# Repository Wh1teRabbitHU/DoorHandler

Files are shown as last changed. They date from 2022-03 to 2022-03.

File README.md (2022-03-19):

# DoorHandler
This is a door handler/extender electronic project to monitor (almost) any type of door bells using a light sensor, a transmitter and a receiver module. The light sensor periodically checks the door phone if the signal is lit or not and sends a pulse to the receiver, which can be anywhere in the house and can provide visual and/or auditory signals to the home owners.

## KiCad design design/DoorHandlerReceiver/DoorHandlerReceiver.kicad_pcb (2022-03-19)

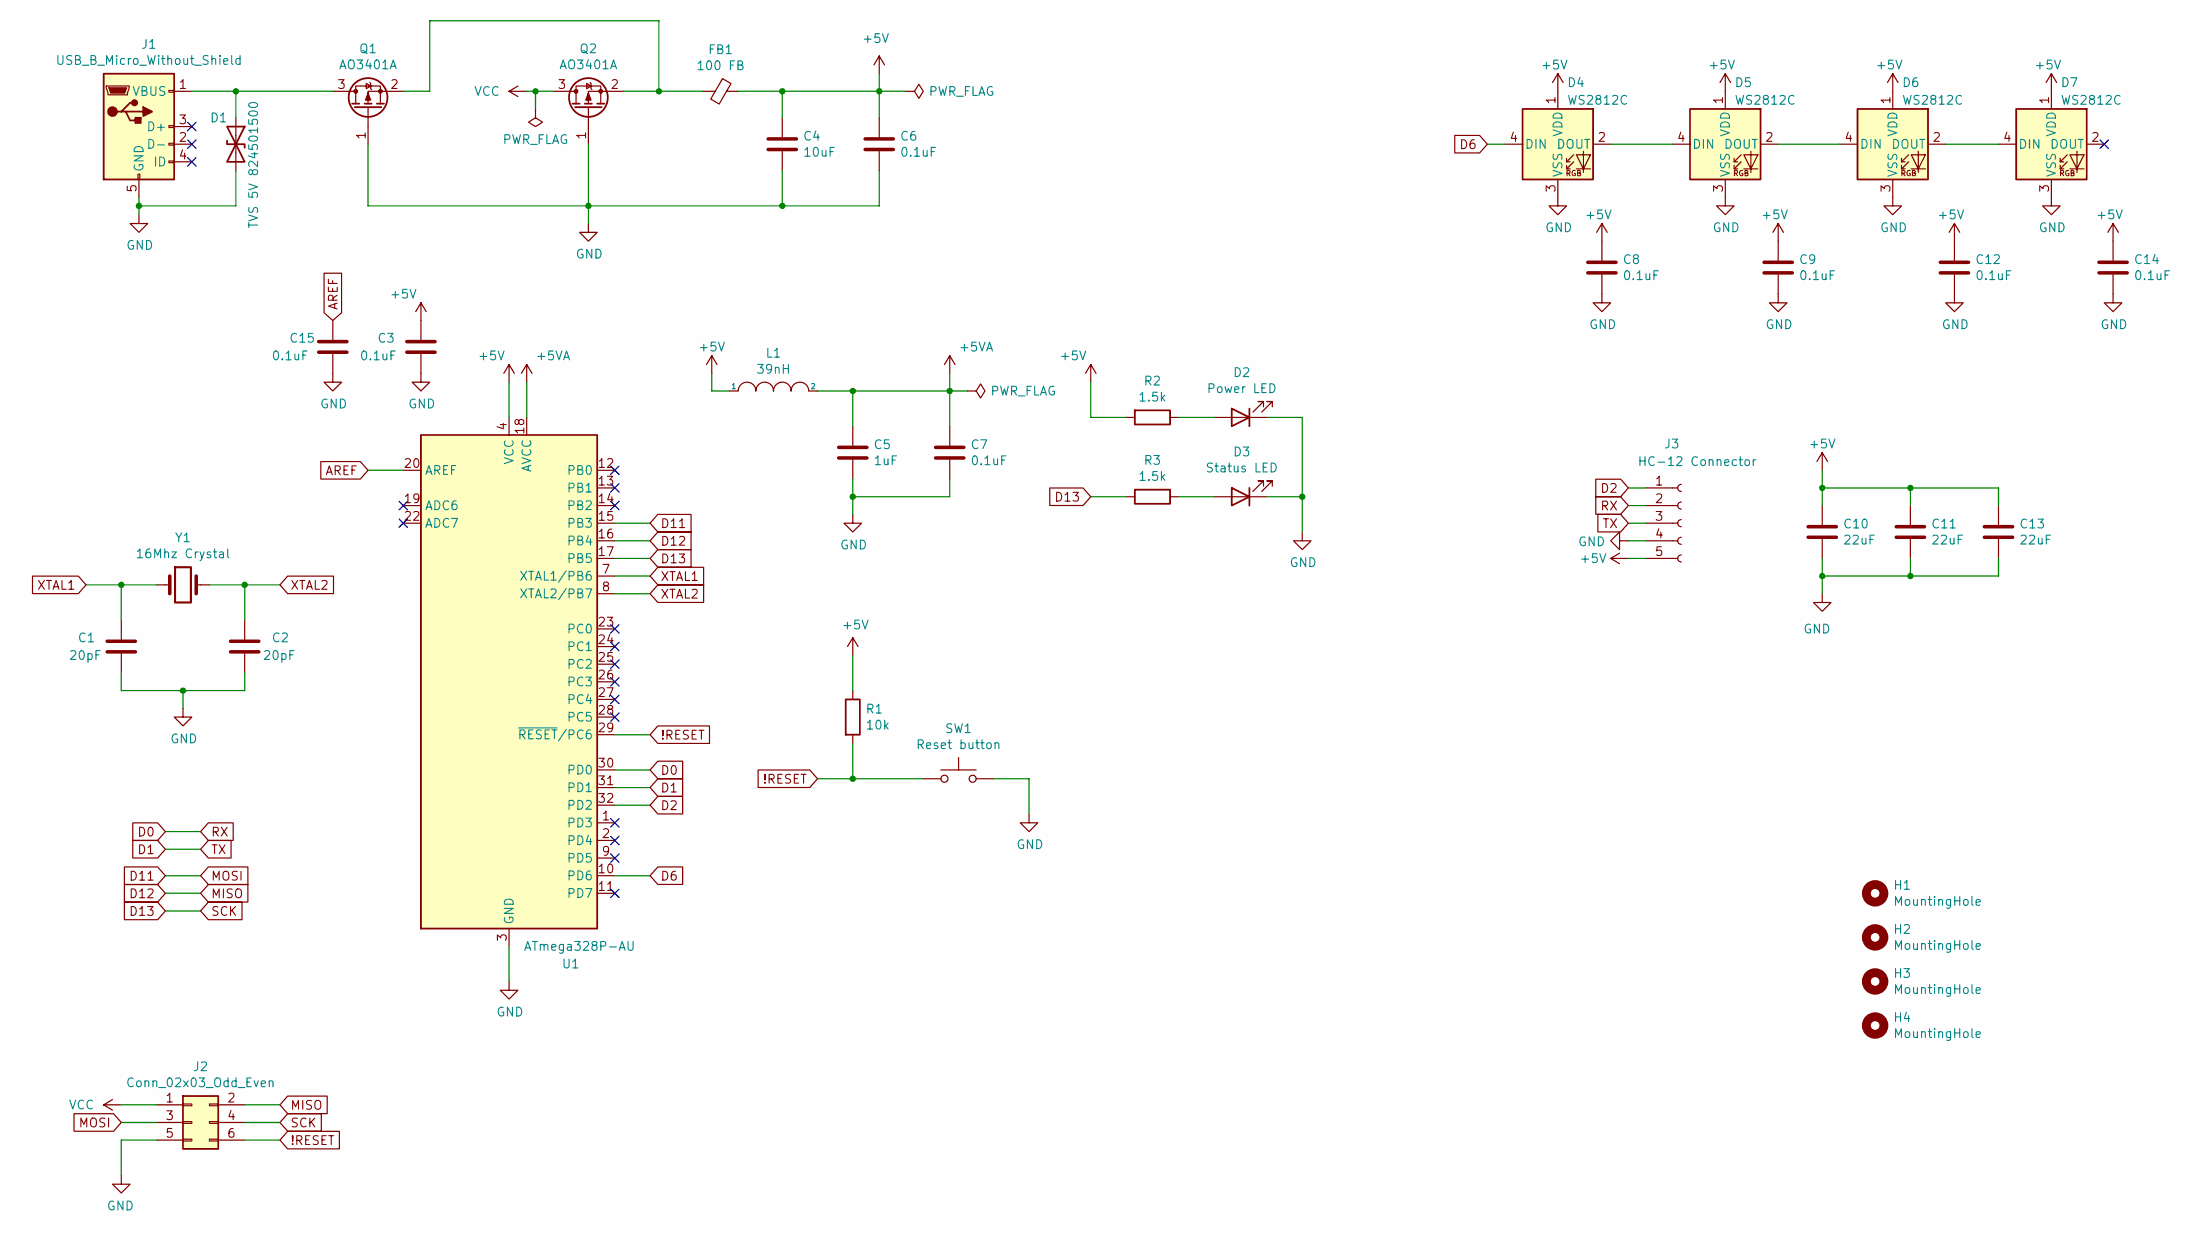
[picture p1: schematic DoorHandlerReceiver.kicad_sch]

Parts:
C1, C2: 20pF; C_0805_2012Metric
C3, C6, C7, C8, C9, C12, C14, C15: 0.1uF; C_0805_2012Metric
C4: 10uF; C_1206_3216Metric
C5: 1uF; C_0805_2012Metric
C10, C11, C13: 22uF; C_0805_2012Metric
D1: TVS 5V 824501500; D_SMA
D2: Power LED; LED_0603_1608Metric
D3: Status LED; LED_0603_1608Metric
D4, D5, D6, D7: WS2812C; LED_WS2812B_PLCC4_5.0x5.0mm_P3.2mm
FB1: 100 FB; L_0805_2012Metric_Pad1.05x1.20mm_HandSolder
H1, H2, H3, H4: MountingHole; MountingHole_3.2mm_M3_Pad_Via
J1: USB_B_Micro_Without_Shield; Micro_USB_B_Female
J2: Conn_02x03_Odd_Even; PinSocket_2x03_P2.54mm_Vertical
J3: HC-12 Connector; PinSocket_1x05_P2.54mm_Vertical
L1: 39nH; L_0805_2012Metric_Pad1.15x1.40mm_HandSolder
Q1, Q2: AO3401A; SOT-23
R1: 10k; R_1206_3216Metric
R2, R3: 1.5k; R_1206_3216Metric
SW1: Reset button; SW_SPST_TL3342
U1: ATmega328P-AU; TQFP-32_7x7mm_P0.8mm
Y1: 16Mhz Crystal; Crystal_HC49-U_Vertical

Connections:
!RESET: J2.6, R1.2, SW1.1, U1.29 (~RESET/PC6)
+5V: C3.1, C4.1, C6.1, C8.1, C9.1, C10.1, C11.1, C12.1, C13.1, C14.1, D4.1 (VDD), D5.1 (VDD), D6.1 (VDD), D7.1 (VDD), FB1.1, J3.5, L1.1, R1.1, R2.2, U1.4 (VCC), U1.6 (VCC)
+5VA: C5.1, C7.1, L1.2, U1.18 (AVCC)
AREF: C15.1, U1.20 (AREF)
D0: J3.2, U1.30 (PD0)
D1: J3.3, U1.31 (PD1)
D2: J3.1, U1.32 (PD2)
D6: D4.4 (DIN), U1.10 (PD6)
D11: J2.3, U1.15 (PB3)
D12: J2.2, U1.16 (PB4)
D13: J2.4, R3.2, U1.17 (PB5)
GND: C1.2, C2.2, C3.2, C4.2, C5.2, C6.2, C7.2, C8.2, C9.2, C10.2, C11.2, C12.2, C13.2, C14.2, C15.2, D1.2 (A2), D2.1 (K), D3.1 (K), D4.3 (VSS), D5.3 (VSS), D6.3 (VSS), D7.3 (VSS), J1.5 (GND), J2.5, J3.4, Q1.1 (G), Q2.1 (G), SW1.2, U1.3 (GND), U1.5 (GND), U1.21 (GND)
unnamed: D1.1 (A1), J1.1 (VBUS), Q1.3 (D)
unnamed: D2.2 (A), R2.1
unnamed: D3.2 (A), R3.1
unnamed: D4.2 (DOUT), D5.4 (DIN)
unnamed: D5.2 (DOUT), D6.4 (DIN)
unnamed: D6.2 (DOUT), D7.4 (DIN)
unnamed: FB1.2, Q1.2 (S), Q2.2 (S)
VCC: J2.1, Q2.3 (D)
XTAL1: C1.1, U1.7 (XTAL1/PB6), Y1.1
XTAL2: C2.1, U1.8 (XTAL2/PB7), Y1.2

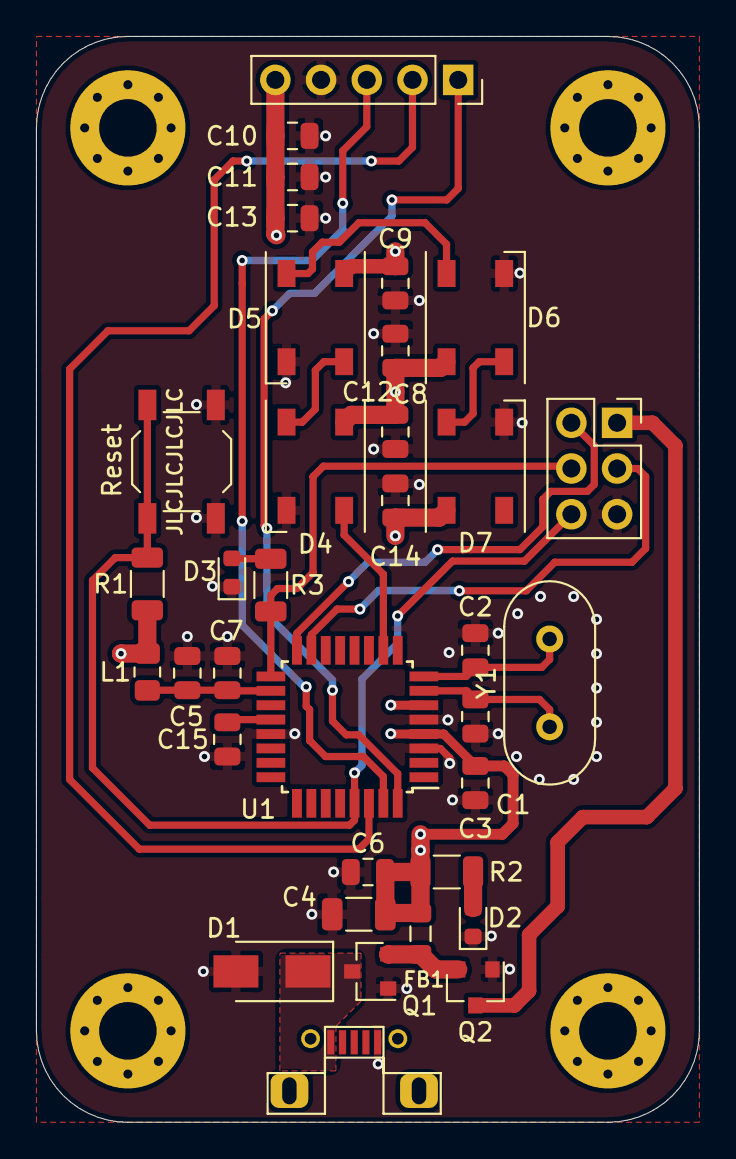
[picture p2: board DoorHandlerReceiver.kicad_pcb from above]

Board: 4 copper layers, 36.8 x 60.3 mm, 39 parts (0 on the bottom side), 22 nets.

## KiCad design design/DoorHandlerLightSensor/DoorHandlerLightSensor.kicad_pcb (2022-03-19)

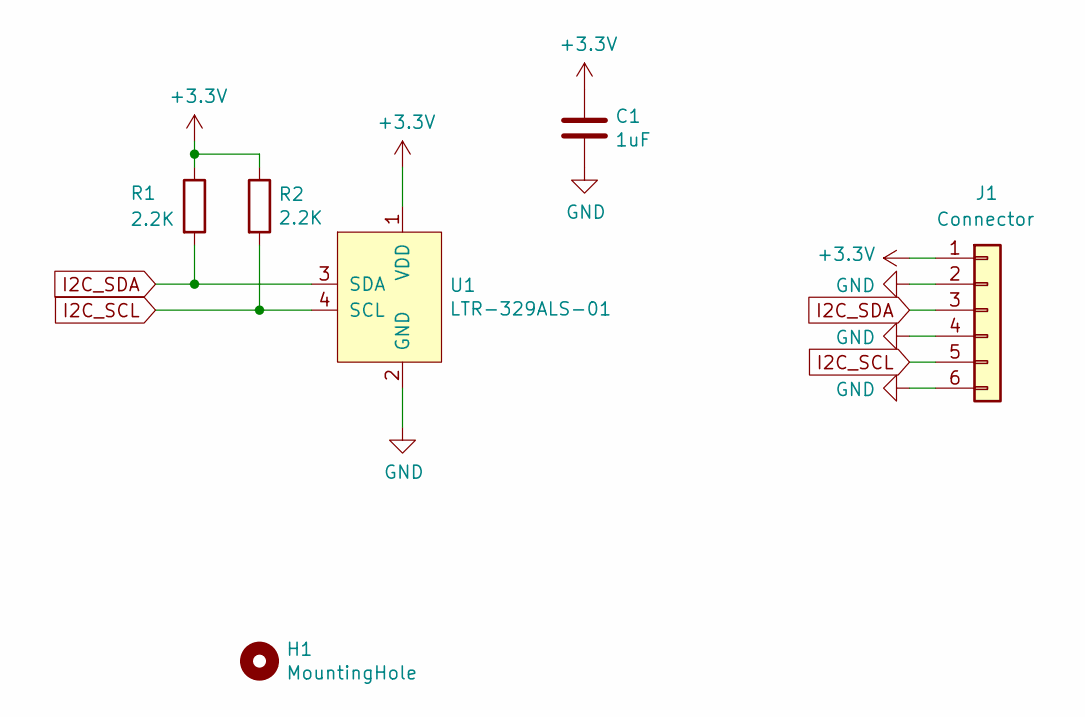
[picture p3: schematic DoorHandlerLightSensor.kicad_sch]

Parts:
C1: 1uF; C_0805_2012Metric
H1: MountingHole; MountingHole_3.2mm_M3_Pad_Via
J1: Connector; AFA07-S06FCA-00
R1, R2: 2.2K; R_1206_3216Metric
U1: LTR-329ALS-01

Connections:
+3V3: C1.1, J1.1, R1.1, R2.1, U1.1 (VDD)
GND: C1.2, J1.2, J1.4, J1.6, U1.2 (GND)
I2C_SCL: J1.5, R2.2, U1.4 (SCL)
I2C_SDA: J1.3, R1.2, U1.3 (SDA)

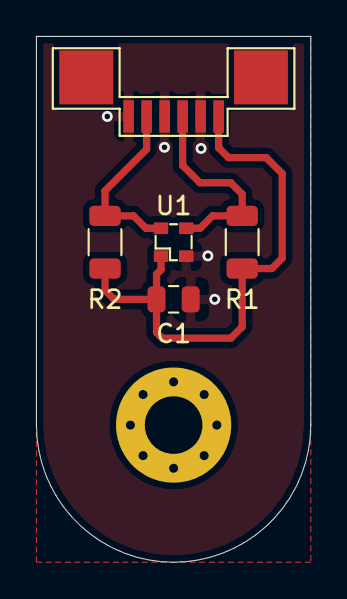
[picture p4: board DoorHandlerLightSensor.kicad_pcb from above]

Board: 2 copper layers, 15.2 x 29.2 mm, 6 parts (0 on the bottom side), 4 nets.

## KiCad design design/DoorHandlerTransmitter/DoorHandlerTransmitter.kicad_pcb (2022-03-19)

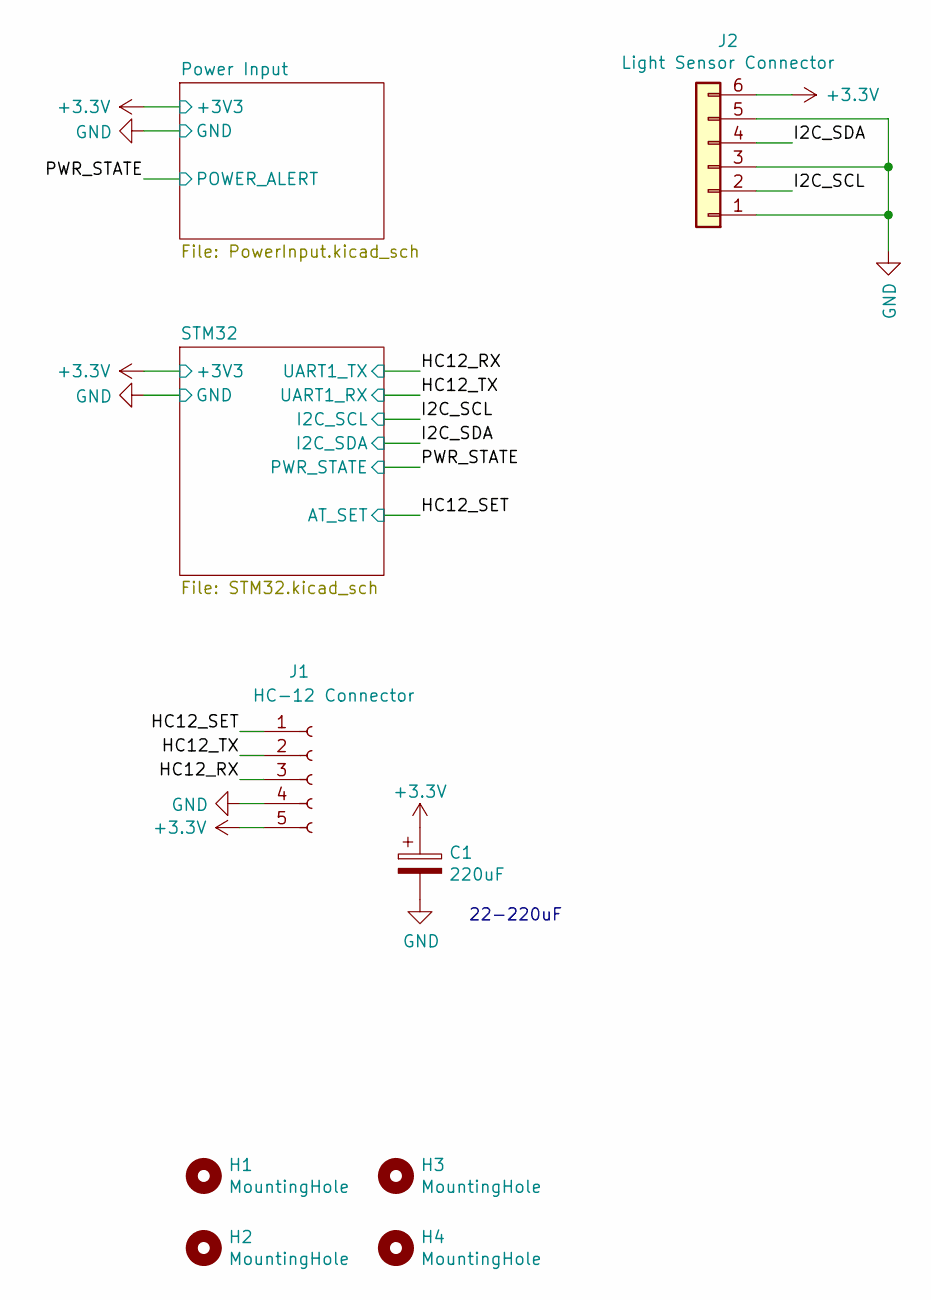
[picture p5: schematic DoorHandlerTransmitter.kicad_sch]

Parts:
C1: 220uF; CP_Elec_8x10.5
H1, H2, H3, H4: MountingHole; MountingHole_3mm_Pad_Via
J1: HC-12 Connector; PinSocket_1x05_P2.54mm_Vertical
J2: Light Sensor Connector; AFA07-S06FCA-00

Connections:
+3V3: C1.1, J1.5, J2.6; also elsewhere on the board
/HC12_RX: J1.3; also elsewhere on the board
/HC12_SET: J1.1; also elsewhere on the board
/HC12_TX: J1.2; also elsewhere on the board
/I2C_SCL: J2.2; also elsewhere on the board
/I2C_SDA: J2.4; also elsewhere on the board
GND: C1.2, J1.4, J2.1, J2.3, J2.5; also elsewhere on the board

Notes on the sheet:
22-220uF

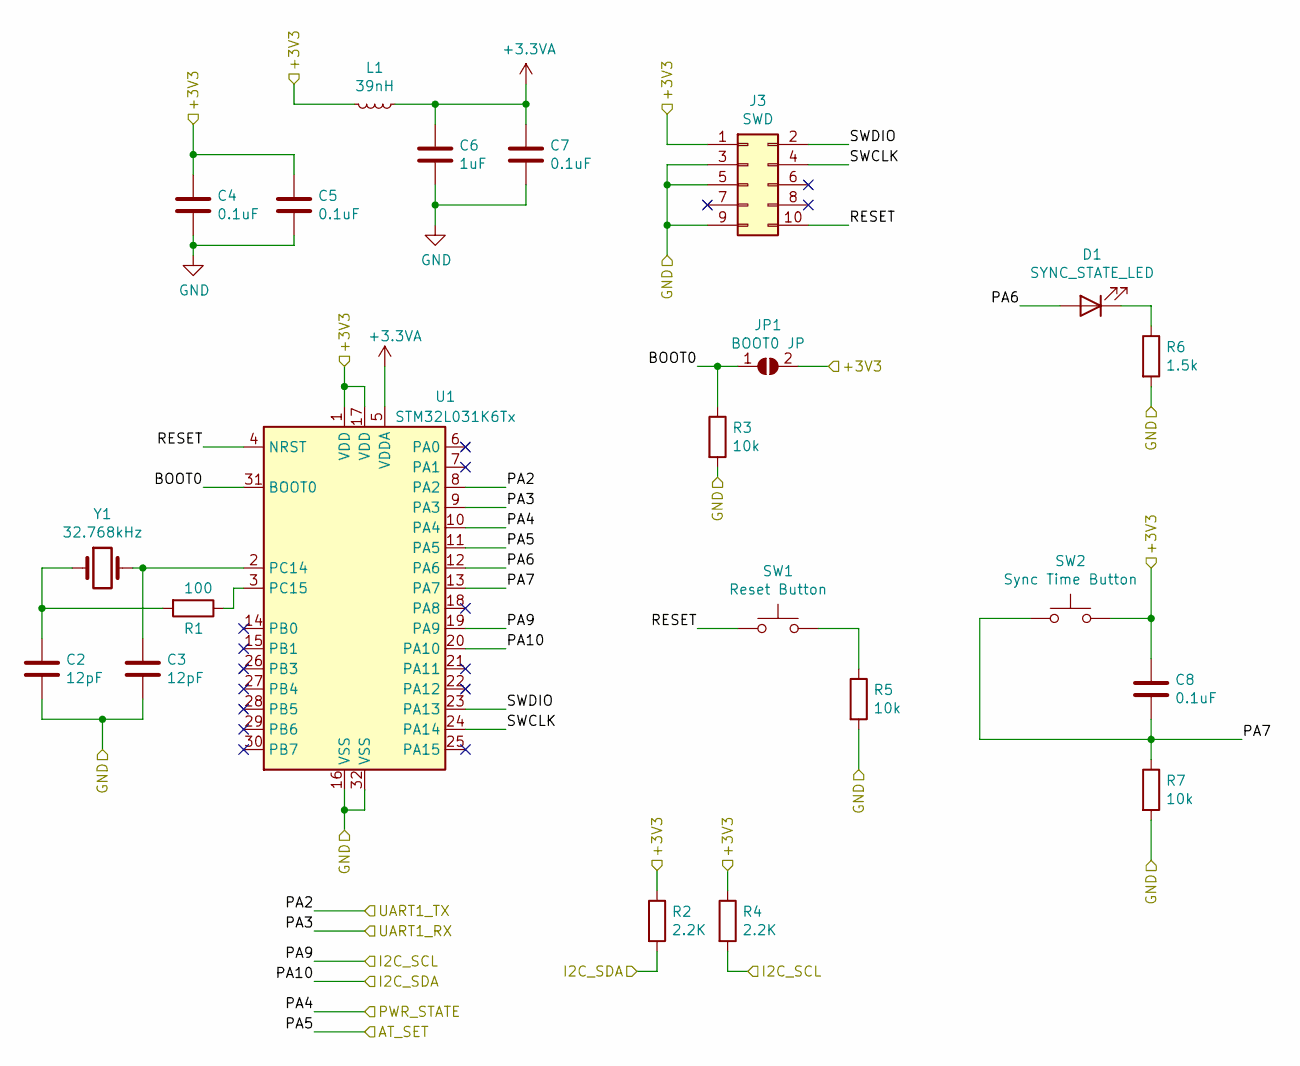
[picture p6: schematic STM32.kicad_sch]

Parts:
C2, C3: 12pF; C_0805_2012Metric
C4, C5, C7, C8: 0.1uF; C_0805_2012Metric
C6: 1uF; C_0805_2012Metric
D1: SYNC_STATE_LED; LED_0603_1608Metric
J3: SWD; PinHeader_2x05_P2.54mm_Vertical
JP1: BOOT0 JP; SolderJumper-2_P1.3mm_Open_RoundedPad1.0x1.5mm
L1: 39nH; L_0805_2012Metric_Pad1.15x1.40mm_HandSolder
R1: 100; R_1206_3216Metric
R2, R4: 2.2K; R_1206_3216Metric
R3, R5, R7: 10k; R_1206_3216Metric
R6: 1.5k; R_1206_3216Metric
SW1: Reset Button; SW_SPST_TL3342
SW2: Sync Time Button; SW_SPST_TL3342
U1: STM32L031K6Tx; LQFP-32_7x7mm_P0.8mm
Y1: 32.768kHz; Crystal_Round_D1.5mm_Vertical

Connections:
+3.3VA: C6.1, C7.1, L1.1, U1.5 (VDDA)
+3V3: C4.1, C5.1, C8.1, J3.1, JP1.2 (B), L1.2, R2.1, R4.1, SW2.2, U1.1 (VDD), U1.17 (VDD); also elsewhere on the board
/HC12_RX: U1.8 (PA2); also elsewhere on the board
/HC12_SET: U1.11 (PA5); also elsewhere on the board
/HC12_TX: U1.9 (PA3); also elsewhere on the board
/I2C_SCL: R4.2, U1.19 (PA9); also elsewhere on the board
/I2C_SDA: R2.2, U1.20 (PA10); also elsewhere on the board
/PWR_STATE: U1.10 (PA4); also elsewhere on the board
/STM32/BOOT0: JP1.1 (A), R3.1, U1.31 (BOOT0)
/STM32/PA6: D1.2 (A), U1.12 (PA6)
/STM32/PA7: C8.2, R7.1, SW2.1, U1.13 (PA7)
/STM32/RESET: J3.10, SW1.1, U1.4 (NRST)
/STM32/SWCLK: J3.4, U1.24 (PA14)
/STM32/SWDIO: J3.2, U1.23 (PA13)
GND: C2.2, C3.2, C4.2, C5.2, C6.2, C7.2, J3.3, J3.5, J3.9, R3.2, R5.2, R6.2, R7.2, U1.16 (VSS), U1.32 (VSS); also elsewhere on the board
unnamed: C2.1, R1.2, Y1.1
unnamed: C3.1, U1.2 (PC14), Y1.2
unnamed: D1.1 (K), R6.1
unnamed: R1.1, U1.3 (PC15)
unnamed: R5.1, SW1.2

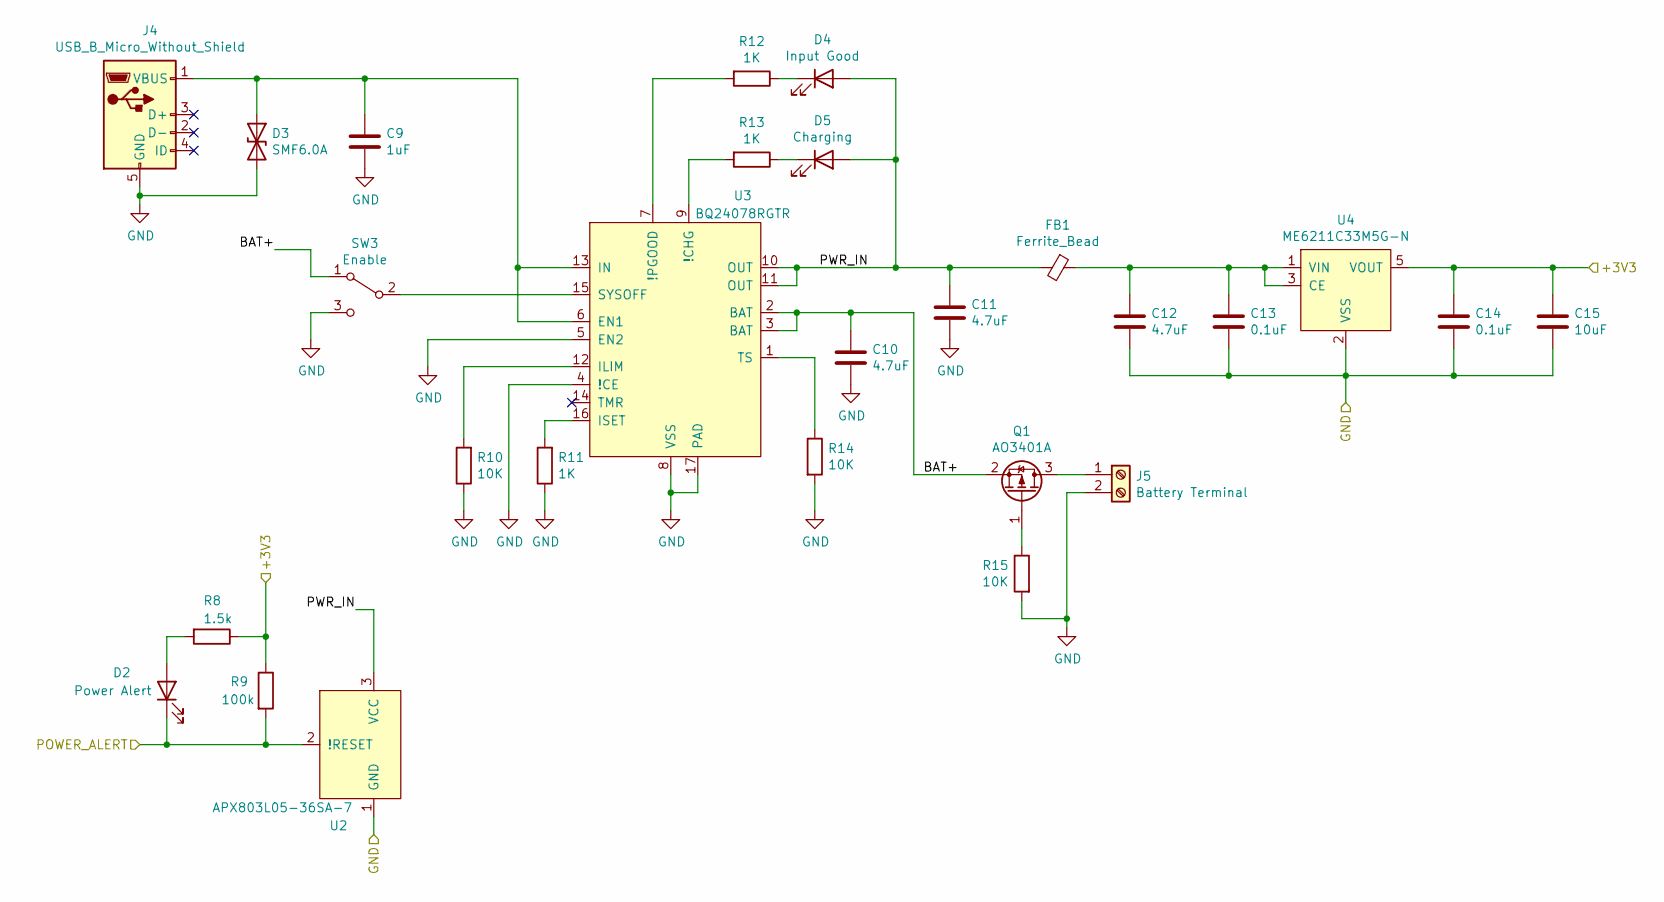
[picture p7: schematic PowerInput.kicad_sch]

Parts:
C9: 1uF; C_0805_2012Metric
C10, C11, C12: 4.7uF; C_0805_2012Metric
C13, C14: 0.1uF; C_0805_2012Metric
C15: 10uF; C_1206_3216Metric
D2: Power Alert; LED_0603_1608Metric
D3: SMF6.0A; D_SOD-123F
D4: Input Good; LED_0603_1608Metric
D5: Charging; LED_0603_1608Metric
FB1: Ferrite_Bead; L_0805_2012Metric_Pad1.15x1.40mm_HandSolder
J4: USB_B_Micro_Without_Shield; Micro_USB_B_Female
J5: Battery Terminal; Hirose_DF13-02P-1.25DSA_1x02_P1.25mm_Vertical
Q1: AO3401A; SOT-23
R8: 1.5k; R_1206_3216Metric
R9: 100k; R_1206_3216Metric
R10, R14, R15: 10K; R_1206_3216Metric
R11, R12, R13: 1K; R_1206_3216Metric
SW3: Enable; Toggle-Switch-SK12D07VG4
U2: APX803L05-36SA-7; SOT-23W_Handsoldering
U3: BQ24078RGTR; VQFN-16-1EP_3x3mm_P0.5mm_EP1.45x1.45mm
U4: ME6211C33M5G-N; SOT-23-5

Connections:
+3V3: C14.1, C15.1, R8.1, R9.1, U4.5 (VOUT); also elsewhere on the board
/PWR_STATE: D2.1 (K), R9.2, U2.2 (!RESET); also elsewhere on the board
/Power Input/BAT+: C10.1, Q1.2 (S), SW3.1 (A), U3.2 (BAT), U3.3 (BAT)
/Power Input/PWR_IN: C11.1, D4.2 (A), D5.2 (A), FB1.2, U2.3 (VCC), U3.10 (OUT), U3.11 (OUT)
GND: C9.2, C10.2, C11.2, C12.2, C13.2, C14.2, C15.2, D3.2 (A2), J4.5 (GND), J5.2, R10.1, R11.1, R14.2, R15.2, SW3.3 (C), U2.1 (GND), U3.4 (!CE), U3.5 (EN2), U3.8 (VSS), U3.17 (PAD), U4.2 (VSS); also elsewhere on the board
unnamed: C9.1, D3.1 (A1), J4.1 (VBUS), U3.6 (EN1), U3.13 (IN)
unnamed: C12.1, C13.1, FB1.1, U4.1 (VIN), U4.3 (CE)
unnamed: D2.2 (A), R8.2
unnamed: D4.1 (K), R12.1
unnamed: D5.1 (K), R13.1
unnamed: J5.1, Q1.3 (D)
unnamed: Q1.1 (G), R15.1
unnamed: R10.2, U3.12 (ILIM)
unnamed: R11.2, U3.16 (ISET)
unnamed: R12.2, U3.7 (!PGOOD)
unnamed: R13.2, U3.9 (!CHG)
unnamed: R14.1, U3.1 (TS)
unnamed: SW3.2 (B), U3.15 (SYSOFF)

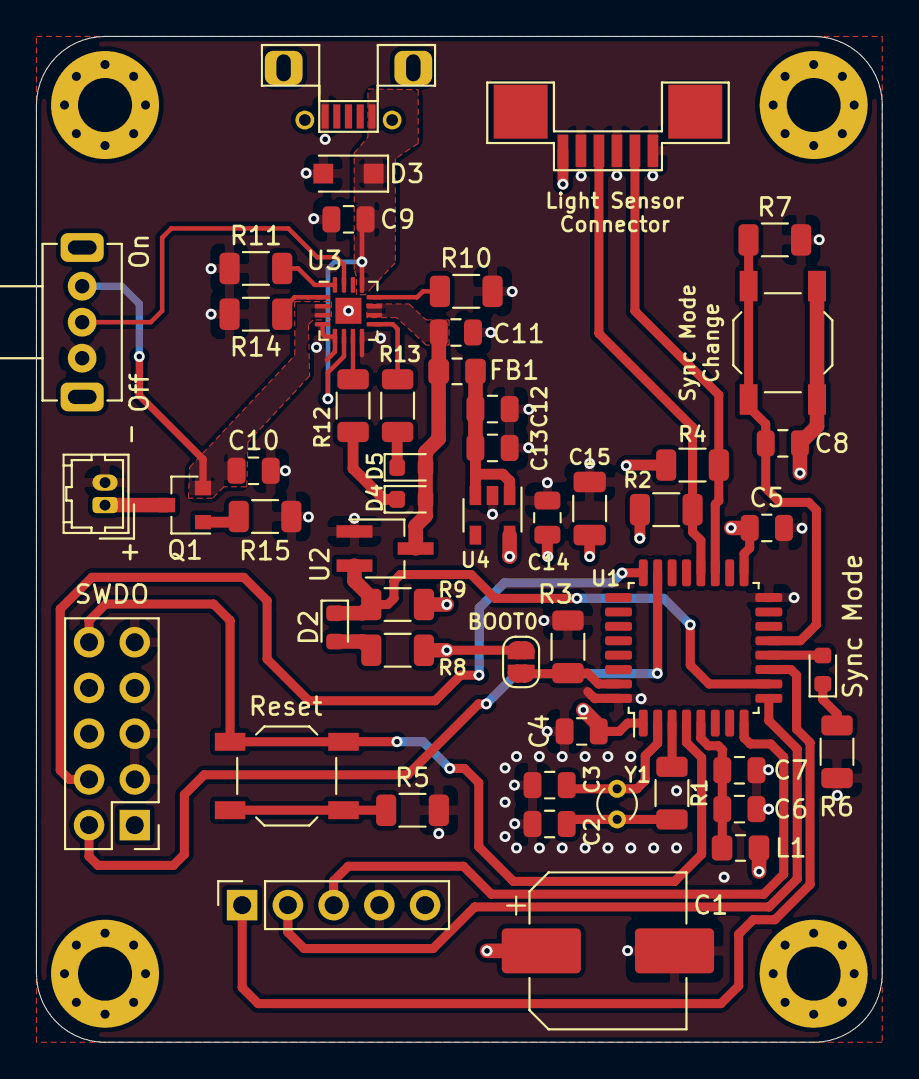
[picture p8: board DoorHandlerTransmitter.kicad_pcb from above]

Board: 4 copper layers, 47.0 x 55.9 mm, 56 parts (0 on the bottom side), 35 nets.

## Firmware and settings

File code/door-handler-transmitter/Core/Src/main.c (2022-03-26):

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
/* Includes ------------------------------------------------------------------*/
#include "main.h"

/* USER CODE BEGIN Includes */
#include "stm32l0xx_it.h"
#include "ltr_329.h"
#include "hc12.h"
/* USER CODE END Includes */

I2C_HandleTypeDef hi2c1;

UART_HandleTypeDef hlpuart1;

TIM_HandleTypeDef htim21;

void SystemClock_Config(void);
static void MX_GPIO_Init(void);
static void MX_I2C1_Init(void);
static void MX_LPUART1_UART_Init(void);
static void MX_TIM21_Init(void);
/**
  * @brief  The application entry point.
  * @retval int
  */
int main(void)
{
  /* MCU Configuration--------------------------------------------------------*/

  /* Reset of all peripherals, Initializes the Flash interface and the Systick. */
  HAL_Init();

  /* Configure the system clock */
  SystemClock_Config();

  /* Initialize all configured peripherals */
  MX_GPIO_Init();
  MX_I2C1_Init();
  MX_LPUART1_UART_Init();
  MX_TIM21_Init();
  /* USER CODE BEGIN 2 */

  // Starting the measurement timer
  IT_setI2CInstance(&hi2c1, &hlpuart1);
  HC12_sleep(&hlpuart1);
  HAL_TIM_Base_Start_IT(&htim21);
  LTR_329_init(&hi2c1);
  LTR_329_writeMeasurementRate(&hi2c1, 0b00100010);

  /* USER CODE END 2 */

  /* Infinite loop */
  /* USER CODE BEGIN WHILE */
  HAL_SuspendTick();
  HAL_PWR_EnableSleepOnExit();
  HAL_PWR_EnterSLEEPMode(PWR_MAINREGULATOR_ON, PWR_SLEEPENTRY_WFI);

  while (1)
  {
    /* USER CODE END WHILE */

    /* USER CODE BEGIN 3 */
	  // With 48x flux:
	  // Light off ch1 = 95 ch0 = 54
	  // Light on ch1 = 1106 ch0 = 822

//	  HAL_Delay(500);
  }
  /* USER CODE END 3 */
}

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


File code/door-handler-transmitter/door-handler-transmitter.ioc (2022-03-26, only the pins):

Mcu.UserName=STM32L031K6Ux
PA10.Signal=I2C1_SDA
PA2.Signal=LPUART1_TX
PA3.Signal=LPUART1_RX
PA5.GPIO_Label=AT_SET
PA5.Signal=GPIO_Output
PA6.GPIO_Label=SYNC_STATE_LED
PA6.Signal=GPIO_Output
PA7.GPIO_Label=SYNC_TIME_BTN
PA7.Signal=GPXTI7
PA9.Signal=I2C1_SCL
PC14-OSC32_IN.Signal=RCC_OSC32_IN
PC15-OSC32_OUT.Signal=RCC_OSC32_OUT

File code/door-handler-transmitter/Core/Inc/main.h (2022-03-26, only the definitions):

#define AT_SET_Pin GPIO_PIN_5
#define AT_SET_GPIO_Port GPIOA
#define SYNC_STATE_LED_Pin GPIO_PIN_6
#define SYNC_STATE_LED_GPIO_Port GPIOA
#define SYNC_TIME_BTN_Pin GPIO_PIN_7
#define SYNC_TIME_BTN_GPIO_Port GPIOA

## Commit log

2022-03-19 Adding DoorHandlerTransmitter PCB design
    [DoorHandlerTransmitter.kicad_pcb, DoorHandlerTransmitter.kicad_sch, DoorHandlerTransmitter.sch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]
2022-03-19 Adding DoorHandlerLightSensor PCB design
    [DoorHandlerLightSensor.kicad_pcb, DoorHandlerLightSensor.kicad_sch, DoorHandlerLightSensor.sch]
2022-03-19 Adding DoorHandlerReceiver PCB design
    [DoorHandlerReceiver.kicad_pcb, DoorHandlerReceiver.kicad_sch, DoorHandlerReceiver.sch]

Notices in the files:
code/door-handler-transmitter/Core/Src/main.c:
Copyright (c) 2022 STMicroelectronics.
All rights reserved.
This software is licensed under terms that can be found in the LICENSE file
